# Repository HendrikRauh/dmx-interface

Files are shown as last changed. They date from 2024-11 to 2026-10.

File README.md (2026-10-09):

# ChaosDMX

> [!NOTE]
> Built with Rust (`esp-hal`, `no_std`, embassy). The legacy Arduino-based firmware lives in the [legacy/arduino branch](https://github.com/HendrikRauh/dmx-interface/tree/legacy/arduino).

ChaosDMX is an open-source, multi-protocol DIY [DMX](https://en.wikipedia.org/wiki/DMX512) interface that acts as a versatile bridge between lighting
control software (e.g., [QLC+](https://www.qlcplus.org/)) and physical stage equipment like fixtures, spotlights, moving heads, and fog machines.
It features two fully configurable ports that can be individually set up as either DMX-Input or DMX-Output.
The interface supports [Art-Net](https://art-net.org.uk/) and [sACN / E1.31](https://entertainment.sundrax.com/blog/ultimate-guide-sacn-control-lighting-over-network) and is able to operate over an Ethernet connection or over Wi-Fi.

______________________________________________________________________

## 🛒 Parts

> [!NOTE]
> We linked some of our components in the table below, feel free to use a vendor and manufacturer of your choice.

| Count | Part |
| ---: | --- |
| 1x | [ESP32 (Lolin S2 Mini)](https://de.aliexpress.com/item/1005006985001838.html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) |
| 2x | [RS485](https://de.aliexpress.com/item/1005006391142478.html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) |
| 1x | [W5500-ETH](https://de.aliexpress.com/item/1005006127400904.html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) |
| 1x | [LED-Button](https://de.aliexpress.com/item/1005003595039032.html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) |
| 1x | ♂️-XLR-socket |
| 1x | ♀️-XLR-socket |

Additionally, you need:

- some wires
- soldering equipment
- 3D-printer
- some screws (see [case](#-case))
- heat shrink tubing

______________________________________________________________________

## 🔌 Wiring

> [!IMPORTANT]
> You need to enable the termination resistor required for DMX for the first and last devices in the chain on your board. On the board we used (RS485 boards) we had to short-circuit `R0` to do so.

The following diagram demonstrates how to wire the components together, in the table below you can see how to connect the pinout of the ESP32 with your project.

Circuit diagram

| GPIO | Usage |
| ---: | --- |
| GND | GND to others |
| 3,3 V | VIN on RS485 |
| 5 V / VBUS | VIN on W5500 |
| 0 | Onboard Button |
| 5 | Ext. Button |
| 7 | Ext. LED |
| 15 | Onboard LED |
| 17 | U1TXD |
| 18 | U1RXD |
| 21 | U0TXD |
| 33 | U0RXD |
| 34 | SPI CS |
| 35 | SPI MOS |
| 36 | SPI SCK |
| 37 | SPI MISO |

______________________________________________________________________

## 🚀 Installation

1. Connect the ESP32 to your computer using a USB cable.
2. Flash the firmware to the ESP32 using the provided [flash tool](https://hendrikrauh.github.io/dmx-interface/flasher/) or by using a command line tool of your choice (e.g., `espflash`).<br>You can find the latest firmware release on the [releases page](https://github.com/HendrikRauh/dmx-interface/releases).
3. Connect to the WiFi network with the [default configuration](#default-config) and access the web interface.

> [!TIP]
> If the ESP32 does not show up as a serial device, you might need to place it in bootloader mode.

______________________________________________________________________

## 📦 Case

All print files can be found in the folder `assets/case`.
Alternatively, you can view the current case on [OnShape](https://cad.onshape.com/documents/7363818fd18bf0cbf094790e/w/52455282b39e47fbde5d0e53/e/9bec98aa83a813dc9a4d6ab2) where you can export the files in a format of your choice.
Feel free to design your own case (and maybe address the [issues with the current one](https://github.com/HendrikRauh/dmx-interface/issues/92)) and share it with us!

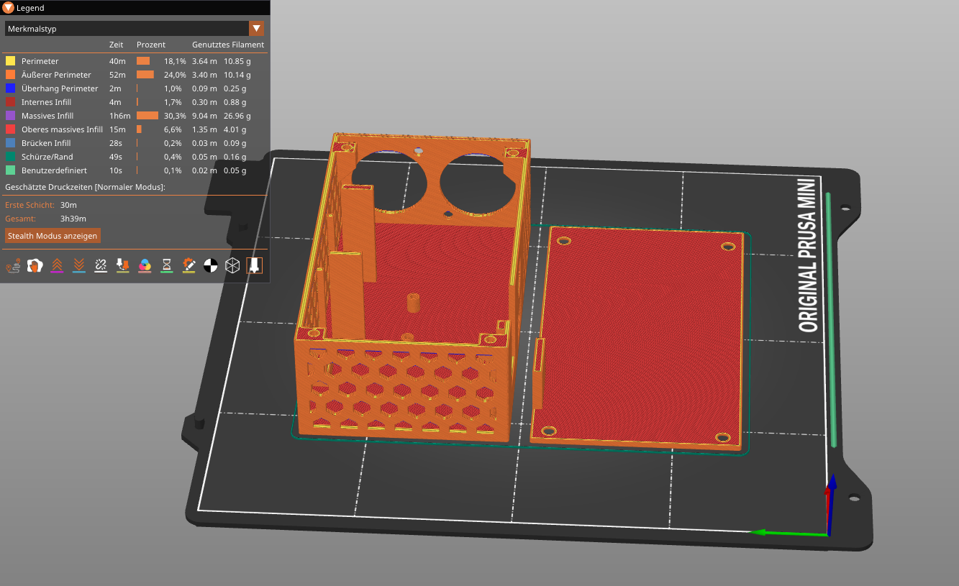
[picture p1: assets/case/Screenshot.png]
Prusa Slicer with case loaded


In addition to the print you will need:

| Count | Part | Location |
| ---: | --- | --- |
| 6x | M2x5 screw | Case lid, ESP32 |
| 2x | M2.5x5 screw | W5500 |
| 4x | M3 screw | XLR sockets |
| 4x | M3 nut | XLR sockets |

______________________________________________________________________

## 💡 Status LED

We have a status LED-Button that shows the current state of the device.

| LED | Description |
| --- | --- |
| off | no power; LED deactivated |
| static | powered on; normal |
| boot | startup |
| slow | warning |
| reset | resetting |
| fast | error |

______________________________________________________________________

## ⚙️ Config

You can configure the device by connecting to the WiFi network and accessing the web interface via the default (listed below) or configured IP address.

### Default config

To reset the settings, hold down the button and connect the ESP to the power supply, the LED will flash rapidly. After 3 seconds the LED will turn solid and the settings are reset. If you release the button early, you will abort the reset and the LED will flash slowly.

| Setting | Value |
| --- | --- |
| Type | WiFi AP |
| SSID | ChaosDMX-□□□□ |
| Password | ChaosDMX |
| IP-Address | 192.168.4.1 |
| DMX0 | OUTPUT; Universe 1 |
| DMX1 | INPUT; Universe 2 |
| LED Brightness | 10 % |

______________________________________________________________________

## 🧑‍💻 Development

We provide a ready-to-use development environment using Nix, but you can also set up the environment manually if you prefer to do so. If you do not want to use Nix make sure to install the required tools listed in the `buildInputs` section in `flake.nix`.
If you are on Windows we recommend using [WSL](https://learn.microsoft.com/en-us/windows/wsl/) and following the instructions below inside the WSL session. You might need to install [usbipd-win](https://github.com/dorssel/usbipd-win#how-to-install) for usage of the usb pass-through

### Setup NIX

For usage of the development environment, having the nix package manager with flakes-support installed on your system is required.
There are two main ways to install the nix package manager on your system.

#### via determinate.systems (recommended)

Have a look at [their website](https://determinate.systems/nix-installer/), there is a single command to run, after this you may restart the system or log out.

#### via nixos.org

If you want to use the bare nix installer visit [nixos.org/download](https://nixos.org/download/) and follow the steps there. When you are done with the installation of nix you need to enable flakes support by adding the following line to your `~/.config/nix/nix.conf`:

```conf
experimental-features = nix-command flakes
```

### Setup direnv (optional)

Optionally, you are able to use direnv to automatically enter the development environment whenever you navigate to the project folder. Further installation instructions can be found on [their website](https://direnv.net/docs/installation.html).

When using it for the first time, you need to allow the `.envrc` file by running `direnv allow` in the project folder.
Afterwards, you can simply navigate to the project folder and you will automatically enter the development environment.

### Commands

This project uses [invoke](https://www.pyinvoke.org/) to simplify running common commands.
Run `inv --list` to see all available tasks or have a look at the `tasks.py` file.

Here is a small selection of the most common tasks:

| Command | Description |
| --- | --- |
| `inv build` | Build the firmware and bundle the website |
| `inv flash` | Build (if needed) and flash the firmware via USB-CDC |
| `inv release` | Build release binaries for all supported targets |
| `inv monitor` | Monitor the serial output |
| `inv docs` | Generate the documentation using rustdoc |
| `inv format` | Run all pre-commit hooks |

> [!NOTE]
> The xtensa target and `-Zbuild-std` are preconfigured in `.cargo/config.toml`,
> so plain `cargo build` / `cargo check` work inside the dev shell.

### Pre-commit hooks

This project uses [git-hooks.nix](https://github.com/cachix/git-hooks.nix) to run code quality, formatting, and consistency checks. When using the dev-shell, these run before your commit and format the code etc.
If you are not using the dev-shell, the action runner will do the check on the repository again and check it for you.

### Troubleshooting

If `inv flash` fails to connect (e.g., a protocol error), power-cycle the board and run `inv flash` again.
On the very first flash (no firmware on the board) you have to enter the bootloader manually: hold **BOOT**, press **RESET**, release **BOOT**, then run `inv flash`. Monitor the firmware output separately with `inv monitor`.

______________________________________________________________________

## 🤝 Contributing

Contributions, issues, and feature requests are welcome!

Feel free to check the [issues page](https://github.com/HendrikRauh/dmx-interface/issues) and the [pull requests](https://github.com/HendrikRauh/dmx-interface/pulls) on GitHub.
Thanks to all contributors who have helped make this project better!

<a href="https://github.com/HendrikRauh/dmx-interface/graphs/contributors">
    Contributors listed with their avatars
</a>

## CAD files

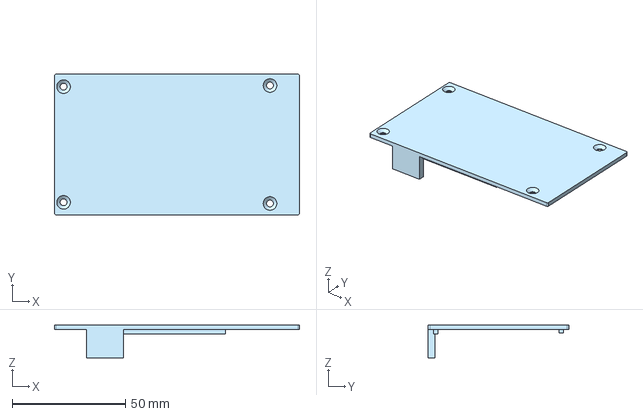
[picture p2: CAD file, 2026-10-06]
assets/case/DMX-Interface_Top.step
108.0 x 62.0 x 14.5 mm

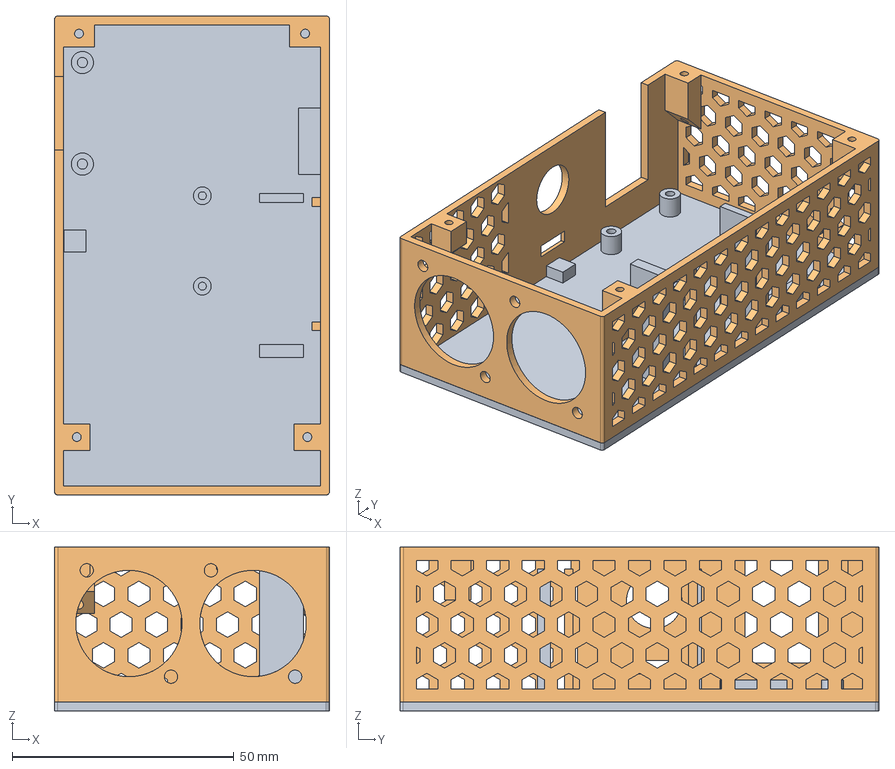
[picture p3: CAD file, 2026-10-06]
assets/case/DMX-Interface_Bottom.step
62.0 x 108.0 x 37.0 mm

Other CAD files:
assets/case/DMX-Interface_Bottom.stl
assets/case/DMX-Interface_Bottom.x_t
assets/case/DMX-Interface_Top.stl
assets/case/DMX-Interface_Top.x_t

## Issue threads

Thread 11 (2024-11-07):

Ability to switch between WLAN and LAN

HendrikRauh, 2024-11-07:

psxde, 2024-11-25:
Duplicates https://github.com/HendrikRauh/dmx-interface/issues/12?

Closed 2024-12-13.

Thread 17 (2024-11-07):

add button and monochrome status light

HendrikRauh, 2024-11-07:

HendrikRauh, 2024-11-10:
what should the button do?
Do we implement a dropdown for different options?

psxde, 2024-11-10:
Already rudimentary included accidentally in 8-ethernet.

- Brightness of status light should be live editable by slider in webui
- status light could be off, slow-blinking, fast-blinking, solid
- pressing button on startup should perform a reset to open AP with default credentials again
- pressing button during the runtime could be end up in a dropdown choosing between switching between eth modes, reset interface, restart interface, blackout, call startup scene etc. - but this should be low priority

psxde, 2024-11-10:
Also we have the builtin status led onboard which can be also used for debugging purposes.

HendrikRauh, 2024-12-13:
Blinking codes are included in the readme

HendrikRauh, 2024-12-13:
@RaffaelW do you make the brightness control?

HendrikRauh, 2024-12-15:
base functions included
button functions = low priority
Opend a new issue for them (#51)

Closed 2024-12-15.

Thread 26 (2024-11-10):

Migrate to LittleFS

psxde, 2024-11-10:
Using `board_build.filesystem = littlefs` in platformio.ini and see examples at https://github.com/espressif/arduino-esp32/blob/master/libraries/LittleFS/examples/LITTLEFS_PlatformIO/src/main.cpp

Closed 2024-11-13.

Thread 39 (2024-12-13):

Reset protection

HendrikRauh, 2024-12-13:
Button should be pressed for 5sec before the reset to prevent reseting by accident

Closed 2024-12-15.

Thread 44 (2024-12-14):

Rework wiring guide

HendrikRauh, 2024-12-14:
CSK > SCK @ Red @ ETH

add 3V rail

Closed 2024-12-15.

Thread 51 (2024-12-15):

Add button actions

HendrikRauh, 2024-12-15:
pressing button during the runtime could be end up in a dropdown choosing between switching between eth modes, reset interface, restart interface, blackout, call startup scene etc

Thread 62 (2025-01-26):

Wrong case design

psxde, 2025-01-26:

HendrikRauh, 2025-01-27:
are the other files correct?
what about the step and x_t?

Closed 2025-01-30.

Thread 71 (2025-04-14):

Reimplement Status LED

HendrikRauh, 2025-04-14:
removed due to problems with dmx (hardwaretimer?)

Closed 2025-04-25.

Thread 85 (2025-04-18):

ESP Connection issue

QuicksilverHgg, 2025-04-18:
Hey guys,
so I finaly soldered my interface today and wanted to give it a testrun.  Unfortunately the ESP is giving me a hard time. So at first it was just not showing up as a possible port in PlatformIO. When I tried to force it into download mode (pressing both buttons and inserting the cable) it does show up, but I get an error:
WARNING: ESP32-S2FNR2 (revision v1.0) chip was placed into download mode using GPIO0.
esptool.py can not exit the download mode over USB. To run the app, reset the chip manually.
To suppress this note, set --after option to 'no_reset'.
*** [uploadfs] Error 1

HendrikRauh, 2025-04-18:
@RaffaelW had the same issue in February

HendrikRauh, 2025-04-26:
To fix the problem with the ESP32 not showing up the steps are usually as below. Sometimes it needs some more tries. (I needed 7 or 8 some times)

---

1. Disconnect the ESP32
2. Press and hold both buttons on the ESP32 (**RST** and **B0**)
3. While holding the buttons plug in the USB-C cable
4. after a few seconds you can release the buttons
5. ESP32 should be in Bootloader mode and visible via Serial
6. Upload the code only ```
```sh
pio run --target upload --environment lolin_s2_mini
```
7. When you get the following warning press the Button **RST** on the ESP
```log
WARNING: ESP32-S2FNR2 (revision v1.0) chip was placed into download mode using GPIO0.
esptool.py can not exit the download mode over USB.
To run the app, reset the chip manually. To suppress this note, set --after option to 'no_reset'.
```
8. Check if you still see the ESP32 listed as a device
```sh
pio device list
```
9. If you still see it you should be fine

---

@QuicksilverHgg pls try it a few times and tell if it had worked

QuicksilverHgg, 2025-04-26:
Thank you. This actually fixed the issue first try.

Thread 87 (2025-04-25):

Use of timers for Websocket and LED

HendrikRauh, 2025-04-25:
Currently, both are implemented using a loop that checks the previous time.
Much better with freeRTOS or something similar?!

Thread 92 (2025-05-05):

Redesign Case

RaffaelW, 2025-05-05:
- [ ] make the onboard buttons of the ESP easier accessible
- [ ] prevent the USB-C Port from moving up when inserting a cable

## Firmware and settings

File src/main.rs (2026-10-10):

//! DMX interface firmware for ESP32-S2 (Lolin S2 Mini).
//!
//! Current scope: status LED on GPIO7 (LEDC PWM, own embassy task), USB-CDC
//! with esptool auto-reset, ring-buffer logging over the CDC port, panic
//! reports persisted across resets, and a `WiFi` network stack (AP with DHCP
//! server or station mode, AP fallback).

#![no_std]
#![no_main]
#![deny(missing_docs)]
#![allow(dead_code)]

extern crate alloc;

// Module docs live as `//!` at the top of each module file. Do NOT also put
// `///` docs on these declarations: rustdoc then resolves the module's
// intra-doc links in this (parent) module's scope and every unqualified link
// breaks — see AGENTS.md "Module docs: `//!` only".
mod boards;
mod config;
mod hardware;
mod logging;
mod net;
mod panic_report;
mod storage;

use embassy_executor::Spawner;
use embassy_time::{Duration, Timer};
use esp_alloc::HeapRegion;
use esp_hal::{
    clock::CpuClock, interrupt::software::SoftwareInterruptControl, timer::timg::TimerGroup,
};

use hardware::led::LedStatus;

esp_bootloader_esp_idf::esp_app_desc!();

/// Clears the panic boot-loop counter once the firmware ran stably for 30 s.
#[embassy_executor::task]
async fn stable_marker() {
    Timer::after(Duration::from_secs(30)).await;
    panic_report::mark_stable();
}

/// Entry point.
#[esp_rtos::main]
async fn main(spawner: Spawner) -> ! {
    let peripherals = esp_hal::init(esp_hal::Config::default().with_cpu_clock(CpuClock::max()));

    // ── Heap allocator ─────────────────────────────────────────────────────
    {
        /// Heap size in bytes (internal RAM — the `WiFi` driver and smoltcp
        /// need ~100 KiB per esp-radio's examples, plus panic-report replay
        /// and NVS reads).
        const HEAP_SIZE: usize = 128 * 1024;
        /// Backing memory for the heap allocator, placed in `.dram2_uninit`
        /// (the 136 KiB region above the stack top that nothing else uses —
        /// see esp-hal's `dram2.x`), keeping the main `dram_seg` free for
        /// the `WiFi` driver's statics and the stack.
        #[unsafe(link_section = ".dram2_uninit")]
        static mut HEAP_MEM: [u8; HEAP_SIZE] = [0u8; HEAP_SIZE];
        let heap_ptr = core::ptr::addr_of_mut!(HEAP_MEM).cast::<u8>();
        // SAFETY: `heap_ptr` points to the whole `HEAP_MEM` array, which is
        // valid for `'static`, exclusively owned by the allocator afterwards,
        // handed over exactly once, and `size > 0`.
        let region = unsafe {
            HeapRegion::new(
                heap_ptr,
                HEAP_SIZE,
                esp_alloc::MemoryCapability::Internal.into(),
            )
        };
        // SAFETY: the heap region is registered exactly once at init time,
        // before anything allocates.
        unsafe {
            esp_alloc::HEAP.add_region(region);
        }
    }

    // ── Embassy scheduler ──────────────────────────────────────────────────
    let timg0 = TimerGroup::new(peripherals.TIMG0);
    let sw_int = SoftwareInterruptControl::new(peripherals.SW_INTERRUPT);
    esp_rtos::start(timg0.timer0, sw_int.software_interrupt0);

    // ── Logging + last-panic report ────────────────────────────────────────
    // Must follow esp_rtos::start (uptime timestamps need the time driver)
    // and precede the USB spawn, so a stored panic report is already in the
    // ring when the first host connects.
    logging::init();
    storage::init(peripherals.FLASH);
    // Load the persisted config and push it into every consumer (LED
    // brightness today, the network stack below).
    let config = storage::load();
    config.apply();
    panic_report::report_last_panic();

    // ── USB-CDC (esptool auto-reset + log drain) ───────────────────────────
    spawner.spawn(
        hardware::usb::task(peripherals.USB0, peripherals.GPIO20, peripherals.GPIO19)
            .expect("USB task spawn failed"),
    );
    spawner.spawn(stable_marker().expect("stable marker spawn failed"));

    // ── Status LED (LEDC PWM, own task) ─────────────────────────────────────
    hardware::led::set(LedStatus::Startup);
    spawner.spawn(
        hardware::led::task(peripherals.LEDC, peripherals.GPIO7).expect("LED task spawn failed"),
    );

    // ── WiFi (AP/STA bring-up + embassy-net stack) ─────────────────────────
    spawner.spawn(net::task(peripherals.WIFI, config, spawner).expect("network task spawn failed"));

    log::info!("Init complete");

    // TODO(phase 6): switch to Ok only once the network is up — the old
    // firmware waited for NETWORK_READY + 2 s before LED_MODE_NORMAL.
    // Until then, keep the Startup breathing visible for 3 s (three full
    // breaths at the 1 s period) before settling into the steady Ok state.
    Timer::after(Duration::from_secs(3)).await;
    hardware::led::set(LedStatus::Ok);

    // No main-loop duties yet — Phase 8 moves system work into tasks.
    loop {
        core::future::pending::<()>().await;
    }
}

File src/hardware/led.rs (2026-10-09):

//! Status LED: LEDC PWM patterns driven by a dedicated embassy task.
//!
//! The LED is the device status indicator. Patterns and timings follow
//! the mockups in `assets/led/*.svg`:
//!
//! | [`LedStatus`] | Pattern                    | Period |
//! | ------------- | -------------------------- | ------ |
//! | `Off`         | dark                       | —      |
//! | `Startup`     | breathing, peak brightness | 1000ms |
//! | `Resetting`   | fast breathing, peak       | 300ms  |
//! | `Ok`          | solid, config brightness   | —      |
//! | `Warning`     | blink, config brightness   | 1000ms |
//! | `Error`       | blink, peak brightness     | 200ms  |
//!
//! All timing lives inside [`task`]; every other task (or interrupt) only
//! calls [`set`] — a lock-free atomic store. Config-driven brightness flows
//! in through [`set_brightness`], pushed by
//! [`crate::config::Config::apply`].

use core::{
    f32::consts::{FRAC_PI_2, TAU},
    sync::atomic::{AtomicU8, Ordering},
};

use embassy_time::{Duration, Instant, Timer};
use esp_hal::{
    ledc::{
        LSGlobalClkSource, Ledc, LowSpeed,
        channel::{self, ChannelHW, ChannelIFace},
        timer::{self, LSClockSource, TimerIFace},
    },
    peripherals::{GPIO7, LEDC},
    time::Rate,
};

/// Breathing period of [`LedStatus::Startup`] (1000 ms per `assets/led/boot.svg`).
const STARTUP_PERIOD_MS: u64 = 1000;
/// Breathing period of [`LedStatus::Resetting`] (300 ms per `assets/led/reset.svg`).
const RESETTING_PERIOD_MS: u64 = 300;
/// Blink period of [`LedStatus::Warning`] (1000 ms per `assets/led/slow.svg`).
const WARNING_PERIOD_MS: u64 = 1000;
/// Blink period of [`LedStatus::Error`] (200 ms per `assets/led/fast.svg`).
const ERROR_PERIOD_MS: u64 = 200;

/// Effect refresh interval.
const TICK: Duration = Duration::from_millis(10);

/// Brightness of the attention states (full scale).
const PEAK_BRIGHTNESS: u8 = 255;

/// Maximum duty count for the configured 14-bit resolution
/// ([`timer::config::Duty::Duty14Bit`], i.e. 2^14 − 1).
///
/// Duty is driven via [`ChannelHW::set_duty_hw`] (raw counts) instead of the
/// percent-based [`ChannelIFace::set_duty`]: the percent API quantizes every
/// update to whole percent, which makes the breathing curve visibly step at
/// low brightness. Raw counts keep all 16384 hardware levels.
const DUTY_MAX: u16 = 0x3FFF;

/// Brightness assumed until [`set_brightness`] delivers the configured
/// value (mirrors `Config::default().led_brightness`).
const DEFAULT_BRIGHTNESS: u8 = 25;

/// Semantic status shown by the LED (timings in the module docs).
#[derive(Debug, Clone, Copy, PartialEq, Eq)]
pub enum LedStatus {
    /// LED off (duty 0).
    Off,
    /// Slow breathing while starting up (1000 ms, peak brightness).
    Startup,
    /// Fast breathing while resetting (300 ms, peak brightness).
    Resetting,
    /// Solid on at the configured brightness.
    Ok,
    /// Slow blink at the configured brightness (1000 ms period).
    Warning,
    /// Fast blink at peak brightness (200 ms period).
    Error,
}

impl LedStatus {
    /// Stable wire encoding for the status atomic.
    const fn code(self) -> u8 {
        match self {
            Self::Off => 0,
            Self::Startup => 1,
            Self::Resetting => 2,
            Self::Ok => 3,
            Self::Warning => 4,
            Self::Error => 5,
        }
    }

    /// Decode a stored status code; unknown codes yield `None`.
    const fn from_code(code: u8) -> Option<Self> {
        match code {
            0 => Some(Self::Off),
            1 => Some(Self::Startup),
            2 => Some(Self::Resetting),
            3 => Some(Self::Ok),
            4 => Some(Self::Warning),
            5 => Some(Self::Error),
            _ => None,
        }
    }
}

/// Requested status; written by [`set`], consumed by [`task`].
static STATUS: AtomicU8 = AtomicU8::new(0);
/// Config-driven brightness (0–255) for [`LedStatus::Ok`] / [`LedStatus::Warning`].
static BRIGHTNESS: AtomicU8 = AtomicU8::new(DEFAULT_BRIGHTNESS);

/// Selects the status pattern.
///
/// Lock-free (`AtomicU8` store), safe to call from any task or interrupt.
/// The effect loop restarts the pattern phase on the next tick, so blink
/// and breathing always start from their initial position.
pub fn set(status: LedStatus) {
    STATUS.store(status.code(), Ordering::Release);
}

/// Sets the config-driven brightness (0–255) used by [`LedStatus::Ok`] and
/// [`LedStatus::Warning`].
///
/// Pushed by [`crate::config::Config::apply`]; the default matches
/// `Config::default().led_brightness`.
pub fn set_brightness(brightness: u8) {
    BRIGHTNESS.store(brightness, Ordering::Release);
}

/// Runs the status-LED effect loop, owning the LEDC peripheral.
///
/// Configure the LEDC timer/channel once, then apply [`set`] statuses at
/// will — the loop picks up every change on its next 10 ms tick.
///
/// # Panics
///
/// Panics if the LEDC timer or channel fails to configure (should not
/// happen on a healthy peripheral).
#[embassy_executor::task]
pub async fn task(ledc: LEDC<'static>, pin: GPIO7<'static>) -> ! {
    let mut ledc = Ledc::new(ledc);
    ledc.set_global_slow_clock(LSGlobalClkSource::APBClk);

    let mut timer0 = ledc.timer::<LowSpeed>(timer::Number::Timer0);
    timer0
        .configure(timer::config::Config {
            duty: timer::config::Duty::Duty14Bit,
            clock_source: LSClockSource::APBClk,
            frequency: Rate::from_khz(1),
        })
        .expect("LEDC timer0 config failed");

    let mut channel = ledc.channel(channel::Number::Channel0, pin);
    channel
        .configure(channel::config::Config {
            timer: &timer0,
            duty_pct: 0,
            drive_mode: esp_hal::gpio::DriveMode::PushPull,
        })
        .expect("LEDC channel0 config failed");

    let mut current = current_status();
    let mut phase = Instant::now();

    loop {
        let status = current_status();
        if status != current {
            current = status;
            phase = Instant::now();
        }
        let brightness = BRIGHTNESS.load(Ordering::Acquire);
        apply(&channel, status, brightness, phase.elapsed().as_millis());
        Timer::after(TICK).await;
    }
}

/// Reads the requested status; unknown codes fall back to [`LedStatus::Off`].
fn current_status() -> LedStatus {
    LedStatus::from_code(STATUS.load(Ordering::Acquire)).unwrap_or(LedStatus::Off)
}
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

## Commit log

2024-10-24 removed code that is currently not needed
    maybe needed later but bloats the code currently
2024-10-24 added switch between input and output
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2024-11-03 DMX-16 added the circuit diagram
2024-11-05 implemented switch between wifi station and wifi access point
2024-11-10 Add case cad files from onshape
    [DMX-Interface_Bottom.step, DMX-Interface_Bottom.stl, DMX-Interface_Bottom.x_t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]
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2024-11-10 analogWrite should also use ledc library; also added auto mac address for ethernet
2024-11-15 Added digital circuit-diagram Fixes #10
2024-12-13 LED-button in drawing Fixes #41
2024-12-14 Fixed typo and added 3V rail Fixes #44
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2024-12-15 select current ssid by default if connected via wifi-station
2024-12-18 fixed led not blinking
    on first run the led would not blink, due to elif instead of if
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2024-12-19 Temperature converted to int Fixes #57
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2024-12-20 replaced text buttons with icons
2024-12-21 added button action configuration and handling for reset and restart
2024-12-21 added led blink code while resetting config
2025-01-26 Fix #62
    [DMX-Interface_Bottom.stl]
2025-01-30 updated cad-files
    [DMX-Interface_Bottom.step, DMX-Interface_Bottom.stl, DMX-Interface_Bottom.x_t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]
2025-02-01 halb-broken implementation with other dmx driver. out works only on second port, in works on first port very slowly and on the second port fast
2025-02-16 fixed loading button actions
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2025-02-21 fixed accidental reset when restarting the interface via button and keeping the button pressed
2025-03-06 fix: correct typo in interrupt function comment for clarity
2025-04-13 remove blinking led that uses a hardware timer
2025-04-18 W5500 now on 3,3V
    instead of 5V
    fixes #80
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2025-04-18 fixed voltage typo
2025-04-18 Revert "W5500 now on 3,3V"
2025-04-18 fix voltage in README
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2025-04-24 made the led work
    in a rather bad way...
2025-11-15 init esp-idf project
    [partitions.csv]
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2026-03-05 add(tasks): implement reset task to clean project state
    [tasks.py]
2026-03-15 fix(tasks): remove SVG optimization from format task documentation
    [tasks.py]
2026-03-15 fix(tasks): import Exit exception for error handling in tasks
    [tasks.py]
2026-03-16 fix(tasks): remove unused sys import from tasks.py
    [tasks.py]
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2026-03-20 Add link to case section for the screws
2026-05-27 chore(lint): move pre-commit to flake.nix (#115)
    This pull request introduces several significant improvements to the
    project's development workflow and documentation. The most notable
    change is the migration from a manually maintained
    `.pre-commit-config.yaml` to an automated and more robust pre-commit
    check system using `git-hooks.nix` in `flake.nix`. The documentation
    (`README.md`) and supporting files have been updated accordingly to
    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
    [partitions.csv]
2026-05-27 docs(readme): replace LED indicator GIFs with SVGs (#116)
2026-05-30 docs(enhance): enhance the documentation (#122)
    the current branch can be viewed under
    https://hendrikrauh.github.io/dmx-interface/branch/119-enhance-documentation/
    ---------
2026-06-03 fix(inv): invoke scripts fixed
    [tasks.py]
2026-06-04 feat(config): add configuration and basic led (#131)
    fixes #102 #100
2026-06-04 ci(tasks): reset more files, remove cleanbuild task and configure update to also update the nix flake
    [tasks.py]
2026-06-04 chore(tasks): include npm update and add directories to reset task
    [tasks.py]
2026-06-05 chore(cspell): import german dict directly from the nix store instead of symlinking it and cleanup gitignore and the reset task
    [tasks.py]
2026-06-05 feat(button): added button actions (#134)
    fixes #106
    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
2026-06-09 feat(web_server): Implement GET and POST methods /api/config endpoint and implement JSON processing
    - Added new source files for handling configuration routes.
    - Introduced a new function to register an array of URI handlers.
    - Implemented JSON validation and processing framework.
    - Added utility function for reading JSON request bodies.
    - Split methods for setting wifi config to ease setting the values from requests.
    - Add min/max markers to enums.
    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
2026-06-10 build(nix): add npm wrapper to to run npm commands with the correct prefix
    [tasks.py]
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2026-06-21 ci(tasks): fix release task
    [tasks.py]
2026-06-21 ci(release): fix build for release
    [tasks.py]
2026-06-25 refactor(web): directly embed gzipped web files in the firmware and remove storage component, LittleFS dependency and the LittleFS partition
    [partitions.csv]
2026-10-06 wip: rewrite firmware as no_std Rust (esp-hal + embassy)
    Replace the ESP-IDF/C firmware with a no_std Rust implementation for the
    Lolin S2 Mini (xtensa-esp32s2-none-elf):
    - LED effects via LEDC PWM, diagnostic blink on the onboard LED
    - USB-CDC-ACM with software DTR/RTS auto-reset (esptool --before usb-reset)
    - config data model (heapless/serde/postcard) and NVS storage — both
    implemented but not wired into main.rs yet (see TODO.md phases 4-8)
    - drop ESP-IDF build system, C components, Doxygen and LittleFS
    - flake: esp-rs-nix toolchain, invoke tasks on cargo/espflash
    - CI: rustdoc docs deploy (fix step id + docspath stdout), check on
    rust/no-std, cargo-sort --no-format vs taplo confli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
    [DMX-Interface_Bottom.step, DMX-Interface_Bottom.x_t, DMX-Interface_Top.step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]
2026-10-09 chore: replace cargo-check hook with strict clippy and fix violations
    [led.rs, main.rs, tasks.py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]
2026-10-09 fix(tasks): robust USB flashing — auto-detect port, fail-fast, cleanup resilience
    [tasks.py]
2026-10-09 feat(led): dedicated embassy task with status enum and smooth PWM
    Restructure the status LED into its own embassy task owning the LEDC
    peripheral; main only calls led::set(LedStatus::...). Patterns follow
    the assets/led/*.svg mockups (boot 1000ms, reset 300ms, warning 1000ms,
    error 200ms blink) with breathing driven by a libm raised sine over raw
    14-bit duty counts (set_duty_hw) instead of the quantized percent API.
    Config brightness flows in via Config::apply() -> set_brightness().
    The GPIO15 diag toggle in main is gone; onboard LED stays dark.
    [led.rs, main.rs]
2026-10-09 docs: fix stale LED/debug guidance in AGENTS, README and TODO
    - AGENTS: GPIO15 pitfall said the onboard LED is used for debugging,
    but the firmware only drives the external LED on GPIO7 now; document
    raw 14-bit duty (set_duty_hw) in the architecture table
    - README: inv flash no longer starts the monitor; troubleshooting now
    matches the esptool two-run flow (BOOT+RESET first flash, inv monitor)
    - TODO: drop old-IDF-firmware reference for LED timings
2026-10-09 chore: make rustdoc warnings fail pre-commit and fix module docs
    - new `rustdoc` hook runs `invoke docs`, which now sets
    RUSTDOCFLAGS=-D warnings (tasks.py): broken intra-doc links fail
    instead of scrolling by
    - document modules only via `//!`: a `///` doc on the `mod x;`
    declaration plus `//!` module docs makes rustdoc resolve the module
    docs in the parent module's scope, breaking every unqualified
    intra-doc link (and silently muting clippy::doc_markdown on the
    `//!` text)
    - coverage script: skip out-of-line `mod x;`, its docs are the module
    file's `//!` (checked by FILE_DOC)
    - backtick `no_std` in config.rs (surfaced doc_markdown)
    [main.rs, tasks.py]
2026-10-10 chore(deps): update rust crate log to v0.4.34 (no-std) (#157)
    This PR contains the following updates:
    | Package | Type | Update | Change |
    |---|---|---|---|
    | [log](https://redirect.github.com/rust-lang/log) | dependencies |
    patch | `0.4.33` → `0.4.34` |
    ---
    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
2026-10-10 chore(deps): update dependency lucide-preact to v1.55.0 (no-std) (#158)
    > ℹ️ **Note**
    >
    > This PR body was truncated due to platform limits.
    | Package | Change |
    [Age](https://docs.renovatebot.com/merge-confidence/) |
    [Confidence](https://docs.renovatebot.com/merge-confidence/) |
    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
2026-10-10 chore(deps): update dependency oxlint-tsgolint to ^0.25.0 (no-std) (#159)
    |
    [oxlint-tsgolint](https://redirect.github.com/oxc-project/tsgolint#readme)
    | [`^0.23.0` →
    `^0.25.0`](https://renovatebot.com/diffs/npm/oxlint-tsgolint/0.23.0/0.25.0)
    |
    ![age](https://developer.mend.io/api/mc/badges/age/npm/oxlint-tsgolint/0.25.0?slim=true)
    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
2026-10-10 chore(deps): update dependency vite to v8.3.4 (no-std) (#161)
    | [vite](https://vite.dev)
    ([source](https://redirect.github.com/vitejs/vite/tree/HEAD/packages/vite))
    | [`8.0.16` →
    `8.3.4`](https://renovatebot.com/diffs/npm/vite/8.0.16/8.3.4) |
    ![age](https://developer.mend.io/api/mc/badges/age/npm/vite/8.3.4?slim=true)
    ![confidence](https://developer.mend.io/api/mc/badges/confidence/npm/vite/8.0.16/8.3.4?slim=true)
    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
2026-10-10 fix(deps): update rust crate esp-nvs to 0.6 (no-std) (#165)
    | [esp-nvs](https://redirect.github.com/lhemala/esp-nvs) | dependencies
    | minor | `0.5` → `0.6` |
    ### Configuration
    📅 **Schedule**: (in timezone Europe/Berlin)
    - Branch creation
    - "before 4am"
    - Automerge
    - At any time (no schedule defined)
    🚦 **Automerge**: Enabled.
    ♻ **Rebasing**: Whenever PR is behind base branch, or you tick the
    rebase/retry checkbox.
    🔕 **Ignore**: Close this PR and you won't be reminded about this update
    again.
    - [ ] <!-- rebase-check -->If you want to rebase/retry this PR, check
    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
2026-10-10 chore(deps): update dependency oxlint-tsgolint to v7 (no-std) (#172)
    | [`^0.25.0` →
    `^7.0.0`](https://renovatebot.com/diffs/npm/oxlint-tsgolint/0.25.0/7.0.2004)
    ![age](https://developer.mend.io/api/mc/badges/age/npm/oxlint-tsgolint/7.0.2004?slim=true)
    ![confidence](https://developer.mend.io/api/mc/badges/confidence/npm/oxlint-tsgolint/0.25.0/7.0.2004?slim=true)
    📅 **Schedule**: (in time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
2026-10-10 fix(deps): update rust crate esp32s2 to 0.33 (no-std) (#169)
    | [esp32s2](https://redirect.github.com/esp-rs/esp-pacs) | dependencies
    | minor | `0.31` → `0.33` |
    t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
2026-10-10 feat(net): WiFi AP/STA with DHCP server and HTTP/WS backbone
    Access point with a hand-rolled DHCPv4 server (8 leases), station
    mode raced against association/DHCP timeouts with AP fallback and
    runtime reconnect, and an HTTP/WebSocket server on four fixed
    connection slots: embedded single-file UI, GET/POST /api/config as
    DeepPartial merge-patch (wire shape = web/src/types/config.d.ts),
    /ws JSON envelope handlers. Routes and envelopes are a replaceable
    reference for the web contributor; API design, UI and tests stay
    out of this repo (AGENTS.md "Web tier").
    Untested on hardware: the WebSocket endpoints and station mode —
    only the AP path (DHCP lease, static UI, GET/POST /api/config,
    NVS roun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
    [main.rs]
2026-10-11 feat(button): wire power-up factory reset and click actions
2026-10-15 feat(docs): starlight site with issue-driven pages and link validation
    Add a Starlight/Astro site built from docs/ and deployed per branch.
    Site:
    - plugins: build-time GitHub issue tables (label/exclude/state),
    file-tree fences, md-to-route links, image zoom, heading badges
    - starlight-links-validator gates every build, replacing
    scripts/check-site-links.py; frontmatter slugs key pages for the
    repo-root docs/ layout, hero links excluded (base applies at render)
    - base-path middleware, hero/banner component, FileTree styles with
    layer-order fix; AGENTS.md becomes a budgeted doc router
    Content:
    - 14 pages incl. new troubleshooting (status LED effect table, open
    `bug` issues except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
2026-10-24 chore(deps): update dependency oxlint-tsgolint to v7.0.2005 (#205)
    | [`7.0.2004` →
    `7.0.2005`](https://renovatebot.com/diffs/npm/oxlint-tsgolint/7.0.2004/7.0.2005)
    ![age](https://developer.mend.io/api/mc/badges/age/npm/oxlint-tsgolint/7.0.2005?slim=true)
    ![confidence](https://developer.mend.io/api/mc/badges/confidence/npm/oxlint-tsgolint/7.0.2004/7.0.2005?slim=true)
    📅 **Schedule**: (in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
2026-10-24 chore(deps): update rust crate enumset to v1.1.15 (#207)
    | [enumset](https://redirect.github.com/Lymia/enumset) | dependencies |
    patch | `1.1.14` → `1.1.15` |
    ### Release Notes
    <details>
    <summary>Lymia/enumset (enumset)</summary>
    ###
    [`v1.1.15`](https://redirect.github.com/Lymia/enumset/blob/HEAD/RELEASES.md#Version-1115-2026-10-23)
    [Compare
    Source](https://redirect.github.com/Lymia/enumset/compare/v1.1.14...v1.1.15)
    - Fixes a compilation issue on recent versions of Rust caused by enum
    variants named `Output` or `Repr`.
    </details>
    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
2026-11-06 chore(deps): update dependency oxlint-tsgolint to v7.0.2006 (#230)
    | [`7.0.2005` →
    `7.0.2006`](https://renovatebot.com/diffs/npm/oxlint-tsgolint/7.0.2005/7.0.2006)
    ![age](https://developer.mend.io/api/mc/badges/age/npm/oxlint-tsgolint/7.0.2006?slim=true)
    ![confidence](https://developer.mend.io/api/mc/badges/confidence/npm/oxlint-tsgolint/7.0.2005/7.0.2006?slim=true)
    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
